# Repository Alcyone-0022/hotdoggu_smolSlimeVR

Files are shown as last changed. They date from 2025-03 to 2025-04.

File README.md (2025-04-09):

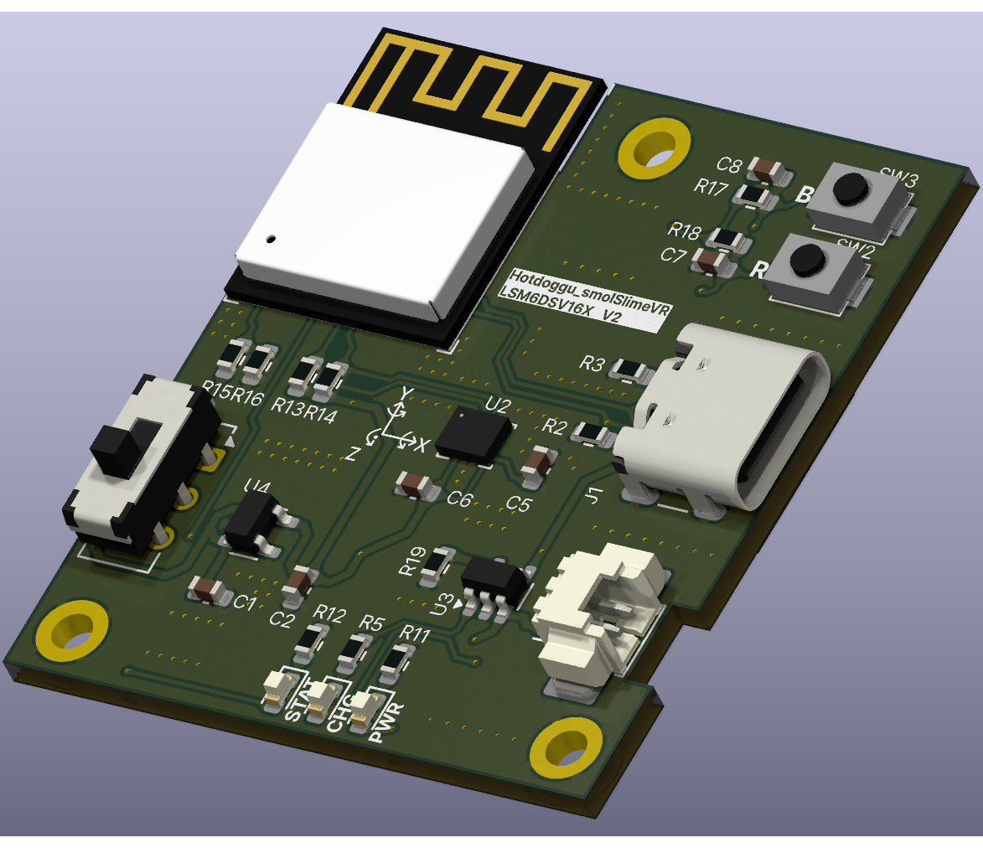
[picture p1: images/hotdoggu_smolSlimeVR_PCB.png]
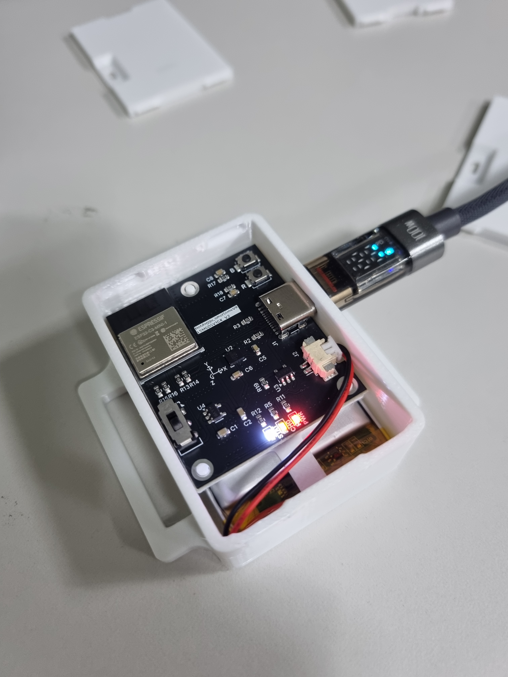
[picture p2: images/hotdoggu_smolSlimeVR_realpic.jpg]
 
# hotdoggu_smolSlimeVR
KiCad project - slimevr tracker using  ESP32-C3-MINI-1, LSM6DSV16X    
Includes 3d-printable case **(for 34\*50\*10(H) Li-Polymer battery)**
# Used Components
### BOM for hotdoggu_smolSlimeVR

| Comment | Designator | Footprint | LCSC | Quantity |
|---|---|---|---|---|
| 10k | R13,R14,R17,R18 | R_0603_1608Metric | C15401 | 4 |
| TYPE-C-31-M-12 | J1 | USB_C_Receptacle_GCT_USB4105-xx-A_16P_TopMnt_Horizontal | C165948 | 1 |
| 1k | R11,R12,R15,R16 | R_0603_1608Metric | C21190 | 4 |
| JS202011CQN | SW1 | SW_CK_JS202011CQN_DPDT_Straight | C221663 | 1 |
| 53261-0271 | J2 | Molex_PicoBlade_53261-0271_1x02-1MP_P1.25mm_Horizontal | C225111 | 1 |
| LED,0603,Red | LED1 | LED_0603_1608Metric | C2286 | 1 |
| 0603,White | LED3 | LED_0603_1608Metric | C2290 | 1 |
| 5.1k, 1% | R2,R3,R5 | R_0603_1608Metric | C23186 | 3 |
| ESP32-C3-MINI-1-H4 | U1 | ESP32-C3-MINI-1 | C2934569 | 1 |
| 2k | R19 | R_0603_1608Metric | C4190 | 1 |
| MCP73831-2-OT | U3 | SOT-23-5 | C424093 | 1 |
| LSM6DSV16X | U2 | LGA-14_3x2.5mm_P0.5mm_LayoutBorder3x4y | C5267406 | 1 |
| 100nF | C5,C6,C7,C8 | C_0603_1608Metric | C66501 | 4 |
| 0603,Yellow | LED2 | LED_0603_1608Metric | C72038 | 1 |
| TS-1088-AR02016 | SW2,SW3 | TS-1088-AR02016 | C720477 | 2 |
| LP5907MFX-3.3 | U4 | SOT-23-5 | C80670 | 1 |
| 10uF | C1,C2 | C_0603_1608Metric | C96446 | 2 | 
### Battery
|Component|Description|Link|
|---|---|----|
|DTP103450|3.7V 1800mAh Li-Polymer battery 34\*50\*10(H)| https://www.devicemart.co.kr/goods/view?no=15285794|
# slimeVR Configuration
**platformio.ini**
```ini
[env:esp32c3]
platform = espressif32 @ 6.7.0
platform_packages =
 framework-arduinoespressif32 @ https://github.com/espressif/arduino-esp32.git#3.0.1
 framework-arduinoespressif32-libs @ https://github.com/espressif/arduino-esp32/releases/download/3.0.1/esp32-arduino-libs-3.0.1.zip
build_flags =
 ${env.build_flags}
 -DESP32C3
board = lolin_c3_mini
```
    
**defines.h**
```C
#define IMU IMU_LSM6DSV
#define SECOND_IMU IMU
#define BOARD BOARD_CUSTOM
#define IMU_ROTATION DEG_0
#define SECOND_IMU_ROTATION DEG_0
#define PRIMARY_IMU_OPTIONAL false
#define SECONDARY_IMU_OPTIONAL true
#define MAX_IMU_COUNT 1
#ifndef IMU_DESC_LIST
#define IMU_DESC_LIST \
    IMU_DESC_ENTRY(IMU,        PRIMARY_IMU_ADDRESS_TWO,   IMU_ROTATION,        PIN_IMU_SCL, PIN_IMU_SDA, PRIMARY_IMU_OPTIONAL, PIN_IMU_INT)
#endif
#define BATTERY_MONITOR BAT_EXTERNAL
#elif BOARD == BOARD_CUSTOM
#define LED_PIN 10
#define LED_INVERTED false
#define PIN_IMU_SDA 3
#define PIN_IMU_SCL 4
#define PIN_IMU_INT 255
#define PIN_IMU_INT_2 255
#define PIN_BATTERY_LEVEL 0
#define BATTERY_SHIELD_RESISTANCE 0
#define BATTERY_SHIELD_R1 1000
#define BATTERY_SHIELD_R2 1000
```

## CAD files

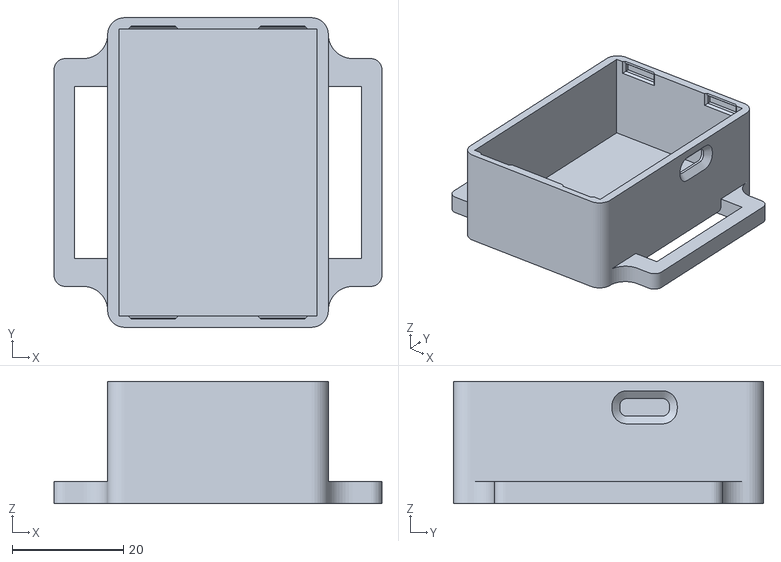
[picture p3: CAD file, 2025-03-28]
STL/main_hotdoggu_smolSlimeVR.stl
59.0 x 55.7 x 22.0

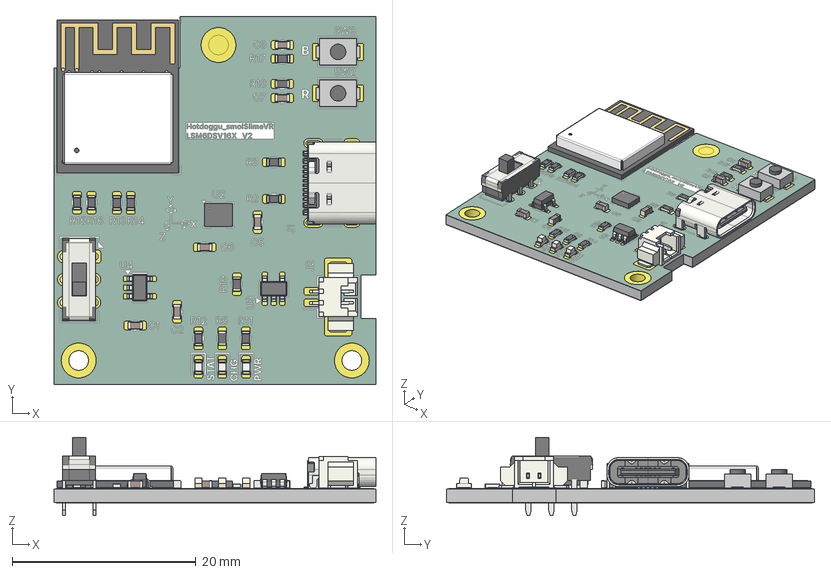
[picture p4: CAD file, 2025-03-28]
hotdoggu_smolSlimeVR_V2.step
35.0 x 40.0 x 8.50 mm
R_0603_1608Metric x 12
SW_CK_JS202011CQN_DPDT_Straight
LGA-14_3x2.5mm_P0.5mm_LayoutBorder3x4y
C_0603_1608Metric x 6
TS-1088-AR020 v2 x 2
TS-1088-AR020 v003 x 2
TS-1088-AR020 v004 x 2
TS-1088-AR020 v005 x 2
Molex_PicoBlade_53261-0271_1x02-1MP_P1.25mm_Horizontal
LED_0603_1608Metric x 3
SOT-23-5 x 2
USB_C_Receptacle_GCT_USB4105-xx-A_16P_TopMnt_Horizontal
DFN1006.STEP^DFN1006.STEP_Submodel-SOD882_part_DesignRootModel_PCB_ ESP32-C3-MINI-1_V1(2)_PCB_ESP32-C3-MINI-1_V1
R0201_20210301.STEP^R0201_20210301.STEP_Submodel-R0201_part_ DesignRootModel_PCB_ESP32-C3-MINI-1_V1(2)_PCB_ESP32-C3-MINI-1_V1 x 3
placementOutline^Submodel-noModelForPart_MINI-ANT-TYPED-H_1968823293_ Submodel-MINI-ANT-TYPED-H_1968823293_part_DesignRootModel_PCB_ ESP32-C3-MINI-1_V1(2)_PCB_E
placementOutline-0^Submodel-noModelForPart_MINI-ANT-TYPED-H_1968823293_ Submodel-MINI-ANT-TYPED-H_1968823293_part_DesignRootModel_PCB_ ESP32-C3-MINI-1_V1(2)_PCB
placementOutline-1^Submodel-noModelForPart_MINI-ANT-TYPED-H_1968823293_ Submodel-MINI-ANT-TYPED-H_1968823293_part_DesignRootModel_PCB_ ESP32-C3-MINI-1_V1(2)_PCB
placementOutline-2^Submodel-noModelForPart_MINI-ANT-TYPED-H_1968823293_ Submodel-MINI-ANT-TYPED-H_1968823293_part_DesignRootModel_PCB_ ESP32-C3-MINI-1_V1(2)_PCB
placementOutline-3^Submodel-noModelForPart_MINI-ANT-TYPED-H_1968823293_ Submodel-MINI-ANT-TYPED-H_1968823293_part_DesignRootModel_PCB_ ESP32-C3-MINI-1_V1(2)_PCB
placementOutline-4^Submodel-noModelForPart_MINI-ANT-TYPED-H_1968823293_ Submodel-MINI-ANT-TYPED-H_1968823293_part_DesignRootModel_PCB_ ESP32-C3-MINI-1_V1(2)_PCB
placementOutline-5^Submodel-noModelForPart_MINI-ANT-TYPED-H_1968823293_ Submodel-MINI-ANT-TYPED-H_1968823293_part_DesignRootModel_PCB_ ESP32-C3-MINI-1_V1(2)_PCB
trace_4^Submodel-MINI-ANT-TYPED-H_1968823293_part_DesignRootModel_PCB_ ESP32-C3-MINI-1_V1(2)_PCB_ESP32-C3-MINI-1_V1
trace_1^Submodel-MINI-ANT-TYPED-H_1968823293_part_DesignRootModel_PCB_ ESP32-C3-MINI-1_V1(2)_PCB_ESP32-C3-MINI-1_V1
C0402_20210301.STEP^C0402_20210301.STEP_Submodel-C0402_part_ DesignRootModel_PCB_ESP32-C3-MINI-1_V1(2)_PCB_ESP32-C3-MINI-1_V1
C0201_20210301.STEP^C0201_20210301.STEP_Submodel-C0201_part_ DesignRootModel_PCB_ESP32-C3-MINI-1_V1(2)_PCB_ESP32-C3-MINI-1_V1 x 11
L0201_20210301.STEP^L0201_20210301.STEP_Submodel-L0201_part_ DesignRootModel_PCB_ESP32-C3-MINI-1_V1(2)_PCB_ESP32-C3-MINI-1_V1 x 2
XTAL3225_20210301.STEP^XTAL3225_20210301.STEP_Submodel-XTAL3225_part_ DesignRootModel_PCB_ESP32-C3-MINI-1_V1(2)_PCB_ESP32-C3-MINI-1_V1
ESP32-C3_20210301.STEP^ESP32-C3_20210301.STEP_Submodel-QFN32_0P5_5_ part_DesignRootModel_PCB_ESP32-C3-MINI-1_V1(2)_PCB_ESP32-C3-MINI-1_V1
uid__4^DesignRootModel_PCB_ESP32-C3-MINI-1_V1(2)_PCB_ESP32-C3-MINI-1_ V1
uid__4-22^DesignRootModel_PCB_ESP32-C3-MINI-1_V1(2)_PCB_ ESP32-C3-MINI-1_V1
uid__4-23^DesignRootModel_PCB_ESP32-C3-MINI-1_V1(2)_PCB_ ESP32-C3-MINI-1_V1
uid__4-24^DesignRootModel_PCB_ESP32-C3-MINI-1_V1(2)_PCB_ ESP32-C3-MINI-1_V1
uid__4-25^DesignRootModel_PCB_ESP32-C3-MINI-1_V1(2)_PCB_ ESP32-C3-MINI-1_V1
uid__4-26^DesignRootModel_PCB_ESP32-C3-MINI-1_V1(2)_PCB_ ESP32-C3-MINI-1_V1
uid__4-27^DesignRootModel_PCB_ESP32-C3-MINI-1_V1(2)_PCB_ ESP32-C3-MINI-1_V1
uid__4-28^DesignRootModel_PCB_ESP32-C3-MINI-1_V1(2)_PCB_ ESP32-C3-MINI-1_V1
uid__4-29^DesignRootModel_PCB_ESP32-C3-MINI-1_V1(2)_PCB_ ESP32-C3-MINI-1_V1
uid__4-30^DesignRootModel_PCB_ESP32-C3-MINI-1_V1(2)_PCB_ ESP32-C3-MINI-1_V1
uid__4-31^DesignRootModel_PCB_ESP32-C3-MINI-1_V1(2)_PCB_ ESP32-C3-MINI-1_V1
uid__4-32^DesignRootModel_PCB_ESP32-C3-MINI-1_V1(2)_PCB_ ESP32-C3-MINI-1_V1
uid__4-33^DesignRootModel_PCB_ESP32-C3-MINI-1_V1(2)_PCB_ ESP32-C3-MINI-1_V1
uid__4-34^DesignRootModel_PCB_ESP32-C3-MINI-1_V1(2)_PCB_ ESP32-C3-MINI-1_V1
uid__4-35^DesignRootModel_PCB_ESP32-C3-MINI-1_V1(2)_PCB_ ESP32-C3-MINI-1_V1
uid__4-36^DesignRootModel_PCB_ESP32-C3-MINI-1_V1(2)_PCB_ ESP32-C3-MINI-1_V1
uid__4-37^DesignRootModel_PCB_ESP32-C3-MINI-1_V1(2)_PCB_ ESP32-C3-MINI-1_V1
uid__4-38^DesignRootModel_PCB_ESP32-C3-MINI-1_V1(2)_PCB_ ESP32-C3-MINI-1_V1
uid__4-39^DesignRootModel_PCB_ESP32-C3-MINI-1_V1(2)_PCB_ ESP32-C3-MINI-1_V1
uid__4-40^DesignRootModel_PCB_ESP32-C3-MINI-1_V1(2)_PCB_ ESP32-C3-MINI-1_V1
uid__4-41^DesignRootModel_PCB_ESP32-C3-MINI-1_V1(2)_PCB_ ESP32-C3-MINI-1_V1
uid__4-42^DesignRootModel_PCB_ESP32-C3-MINI-1_V1(2)_PCB_ ESP32-C3-MINI-1_V1
uid__4-43^DesignRootModel_PCB_ESP32-C3-MINI-1_V1(2)_PCB_ ESP32-C3-MINI-1_V1
uid__4-44^DesignRootModel_PCB_ESP32-C3-MINI-1_V1(2)_PCB_ ESP32-C3-MINI-1_V1
uid__4-45^DesignRootModel_PCB_ESP32-C3-MINI-1_V1(2)_PCB_ ESP32-C3-MINI-1_V1
uid__4-46^DesignRootModel_PCB_ESP32-C3-MINI-1_V1(2)_PCB_ ESP32-C3-MINI-1_V1
uid__4-47^DesignRootModel_PCB_ESP32-C3-MINI-1_V1(2)_PCB_ ESP32-C3-MINI-1_V1
uid__4-48^DesignRootModel_PCB_ESP32-C3-MINI-1_V1(2)_PCB_ ESP32-C3-MINI-1_V1
uid__4-49^DesignRootModel_PCB_ESP32-C3-MINI-1_V1(2)_PCB_ ESP32-C3-MINI-1_V1
uid__4-50^DesignRootModel_PCB_ESP32-C3-MINI-1_V1(2)_PCB_ ESP32-C3-MINI-1_V1
uid__4-51^DesignRootModel_PCB_ESP32-C3-MINI-1_V1(2)_PCB_ ESP32-C3-MINI-1_V1
uid__4-52^DesignRootModel_PCB_ESP32-C3-MINI-1_V1(2)_PCB_ ESP32-C3-MINI-1_V1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

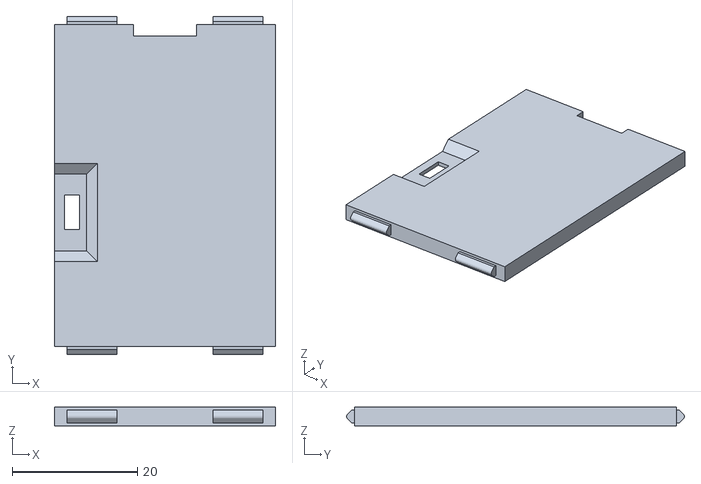
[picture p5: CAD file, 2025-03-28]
STL/Lid_hotdoggu_smolSlimeVR.stl
35.3 x 53.9 x 3.00

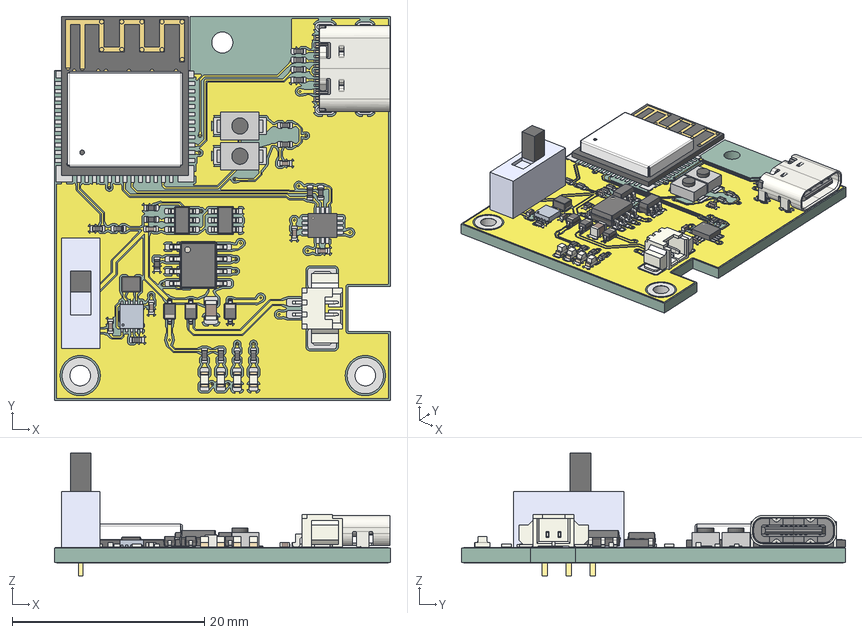
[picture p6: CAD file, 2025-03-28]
hotdoggu_smolSlimeVR.step
35.0 x 40.0 x 12.8 mm
C_0402_1005Metric x 6
USB_C_Receptacle_GCT_USB4105-xx-A_16P_TopMnt_Horizontal
SOT-23-6 x 2
LED_0603_1608Metric x 4
L_Cenker_CKCS201610
R_0402_1005Metric x 18
D_SOD-323 x 3
Molex_PicoBlade_53261-0271_1x02-1MP_P1.25mm_Horizontal
MSL-1C2P SW
TS-1088-AR020 v2 x 2
TS-1088-AR020 v003 x 2
TS-1088-AR020 v004 x 2
TS-1088-AR020 v005 x 2
hotdoggu_smolSlimeVR 1.20.1
C_0805_2012Metric
LGA-14_3x2.5mm_P0.5mm_LayoutBorder3x4y
SOIC-8_3.9x4.9mm_P1.27mm
DFN1006.STEP^DFN1006.STEP_Submodel-SOD882_part_DesignRootModel_PCB_ ESP32-C3-MINI-1_V1(2)_PCB_ESP32-C3-MINI-1_V1
R0201_20210301.STEP^R0201_20210301.STEP_Submodel-R0201_part_ DesignRootModel_PCB_ESP32-C3-MINI-1_V1(2)_PCB_ESP32-C3-MINI-1_V1 x 3
placementOutline^Submodel-noModelForPart_MINI-ANT-TYPED-H_1968823293_ Submodel-MINI-ANT-TYPED-H_1968823293_part_DesignRootModel_PCB_ ESP32-C3-MINI-1_V1(2)_PCB_E
placementOutline-0^Submodel-noModelForPart_MINI-ANT-TYPED-H_1968823293_ Submodel-MINI-ANT-TYPED-H_1968823293_part_DesignRootModel_PCB_ ESP32-C3-MINI-1_V1(2)_PCB
placementOutline-1^Submodel-noModelForPart_MINI-ANT-TYPED-H_1968823293_ Submodel-MINI-ANT-TYPED-H_1968823293_part_DesignRootModel_PCB_ ESP32-C3-MINI-1_V1(2)_PCB
placementOutline-2^Submodel-noModelForPart_MINI-ANT-TYPED-H_1968823293_ Submodel-MINI-ANT-TYPED-H_1968823293_part_DesignRootModel_PCB_ ESP32-C3-MINI-1_V1(2)_PCB
placementOutline-3^Submodel-noModelForPart_MINI-ANT-TYPED-H_1968823293_ Submodel-MINI-ANT-TYPED-H_1968823293_part_DesignRootModel_PCB_ ESP32-C3-MINI-1_V1(2)_PCB
placementOutline-4^Submodel-noModelForPart_MINI-ANT-TYPED-H_1968823293_ Submodel-MINI-ANT-TYPED-H_1968823293_part_DesignRootModel_PCB_ ESP32-C3-MINI-1_V1(2)_PCB
placementOutline-5^Submodel-noModelForPart_MINI-ANT-TYPED-H_1968823293_ Submodel-MINI-ANT-TYPED-H_1968823293_part_DesignRootModel_PCB_ ESP32-C3-MINI-1_V1(2)_PCB
trace_4^Submodel-MINI-ANT-TYPED-H_1968823293_part_DesignRootModel_PCB_ ESP32-C3-MINI-1_V1(2)_PCB_ESP32-C3-MINI-1_V1
trace_1^Submodel-MINI-ANT-TYPED-H_1968823293_part_DesignRootModel_PCB_ ESP32-C3-MINI-1_V1(2)_PCB_ESP32-C3-MINI-1_V1
C0402_20210301.STEP^C0402_20210301.STEP_Submodel-C0402_part_ DesignRootModel_PCB_ESP32-C3-MINI-1_V1(2)_PCB_ESP32-C3-MINI-1_V1
C0201_20210301.STEP^C0201_20210301.STEP_Submodel-C0201_part_ DesignRootModel_PCB_ESP32-C3-MINI-1_V1(2)_PCB_ESP32-C3-MINI-1_V1 x 11
L0201_20210301.STEP^L0201_20210301.STEP_Submodel-L0201_part_ DesignRootModel_PCB_ESP32-C3-MINI-1_V1(2)_PCB_ESP32-C3-MINI-1_V1 x 2
XTAL3225_20210301.STEP^XTAL3225_20210301.STEP_Submodel-XTAL3225_part_ DesignRootModel_PCB_ESP32-C3-MINI-1_V1(2)_PCB_ESP32-C3-MINI-1_V1
ESP32-C3_20210301.STEP^ESP32-C3_20210301.STEP_Submodel-QFN32_0P5_5_ part_DesignRootModel_PCB_ESP32-C3-MINI-1_V1(2)_PCB_ESP32-C3-MINI-1_V1
uid__4^DesignRootModel_PCB_ESP32-C3-MINI-1_V1(2)_PCB_ESP32-C3-MINI-1_ V1
uid__4-22^DesignRootModel_PCB_ESP32-C3-MINI-1_V1(2)_PCB_ ESP32-C3-MINI-1_V1
uid__4-23^DesignRootModel_PCB_ESP32-C3-MINI-1_V1(2)_PCB_ ESP32-C3-MINI-1_V1
uid__4-24^DesignRootModel_PCB_ESP32-C3-MINI-1_V1(2)_PCB_ ESP32-C3-MINI-1_V1
uid__4-25^DesignRootModel_PCB_ESP32-C3-MINI-1_V1(2)_PCB_ ESP32-C3-MINI-1_V1
uid__4-26^DesignRootModel_PCB_ESP32-C3-MINI-1_V1(2)_PCB_ ESP32-C3-MINI-1_V1
uid__4-27^DesignRootModel_PCB_ESP32-C3-MINI-1_V1(2)_PCB_ ESP32-C3-MINI-1_V1
uid__4-28^DesignRootModel_PCB_ESP32-C3-MINI-1_V1(2)_PCB_ ESP32-C3-MINI-1_V1
uid__4-29^DesignRootModel_PCB_ESP32-C3-MINI-1_V1(2)_PCB_ ESP32-C3-MINI-1_V1
uid__4-30^DesignRootModel_PCB_ESP32-C3-MINI-1_V1(2)_PCB_ ESP32-C3-MINI-1_V1
uid__4-31^DesignRootModel_PCB_ESP32-C3-MINI-1_V1(2)_PCB_ ESP32-C3-MINI-1_V1
uid__4-32^DesignRootModel_PCB_ESP32-C3-MINI-1_V1(2)_PCB_ ESP32-C3-MINI-1_V1
uid__4-33^DesignRootModel_PCB_ESP32-C3-MINI-1_V1(2)_PCB_ ESP32-C3-MINI-1_V1
uid__4-34^DesignRootModel_PCB_ESP32-C3-MINI-1_V1(2)_PCB_ ESP32-C3-MINI-1_V1
uid__4-35^DesignRootModel_PCB_ESP32-C3-MINI-1_V1(2)_PCB_ ESP32-C3-MINI-1_V1
uid__4-36^DesignRootModel_PCB_ESP32-C3-MINI-1_V1(2)_PCB_ ESP32-C3-MINI-1_V1
uid__4-37^DesignRootModel_PCB_ESP32-C3-MINI-1_V1(2)_PCB_ ESP32-C3-MINI-1_V1
uid__4-38^DesignRootModel_PCB_ESP32-C3-MINI-1_V1(2)_PCB_ ESP32-C3-MINI-1_V1
uid__4-39^DesignRootModel_PCB_ESP32-C3-MINI-1_V1(2)_PCB_ ESP32-C3-MINI-1_V1
uid__4-40^DesignRootModel_PCB_ESP32-C3-MINI-1_V1(2)_PCB_ ESP32-C3-MINI-1_V1
uid__4-41^DesignRootModel_PCB_ESP32-C3-MINI-1_V1(2)_PCB_ ESP32-C3-MINI-1_V1
uid__4-42^DesignRootModel_PCB_ESP32-C3-MINI-1_V1(2)_PCB_ ESP32-C3-MINI-1_V1
uid__4-43^DesignRootModel_PCB_ESP32-C3-MINI-1_V1(2)_PCB_ ESP32-C3-MINI-1_V1
uid__4-44^DesignRootModel_PCB_ESP32-C3-MINI-1_V1(2)_PCB_ ESP32-C3-MINI-1_V1
uid__4-45^DesignRootModel_PCB_ESP32-C3-MINI-1_V1(2)_PCB_ ESP32-C3-MINI-1_V1
uid__4-46^DesignRootModel_PCB_ESP32-C3-MINI-1_V1(2)_PCB_ ESP32-C3-MINI-1_V1
uid__4-47^DesignRootModel_PCB_ESP32-C3-MINI-1_V1(2)_PCB_ ESP32-C3-MINI-1_V1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

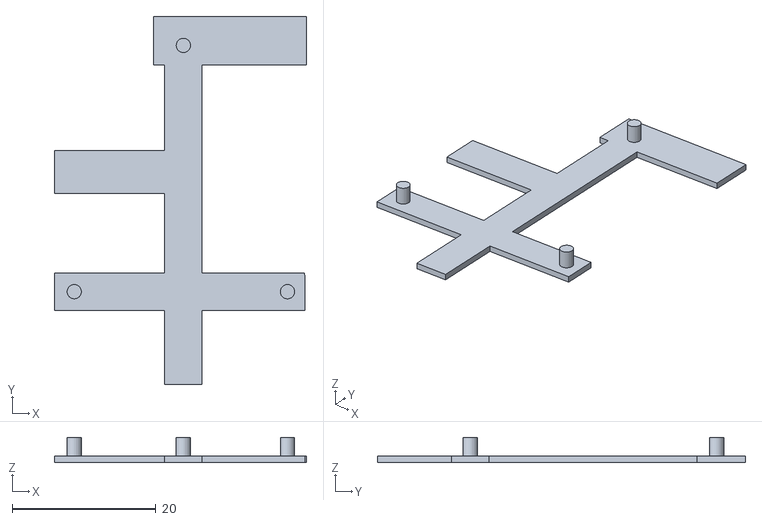
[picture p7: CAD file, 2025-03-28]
STL/spacer_hotdoggu_smolSlimeVR.stl
35.1 x 51.3 x 3.50

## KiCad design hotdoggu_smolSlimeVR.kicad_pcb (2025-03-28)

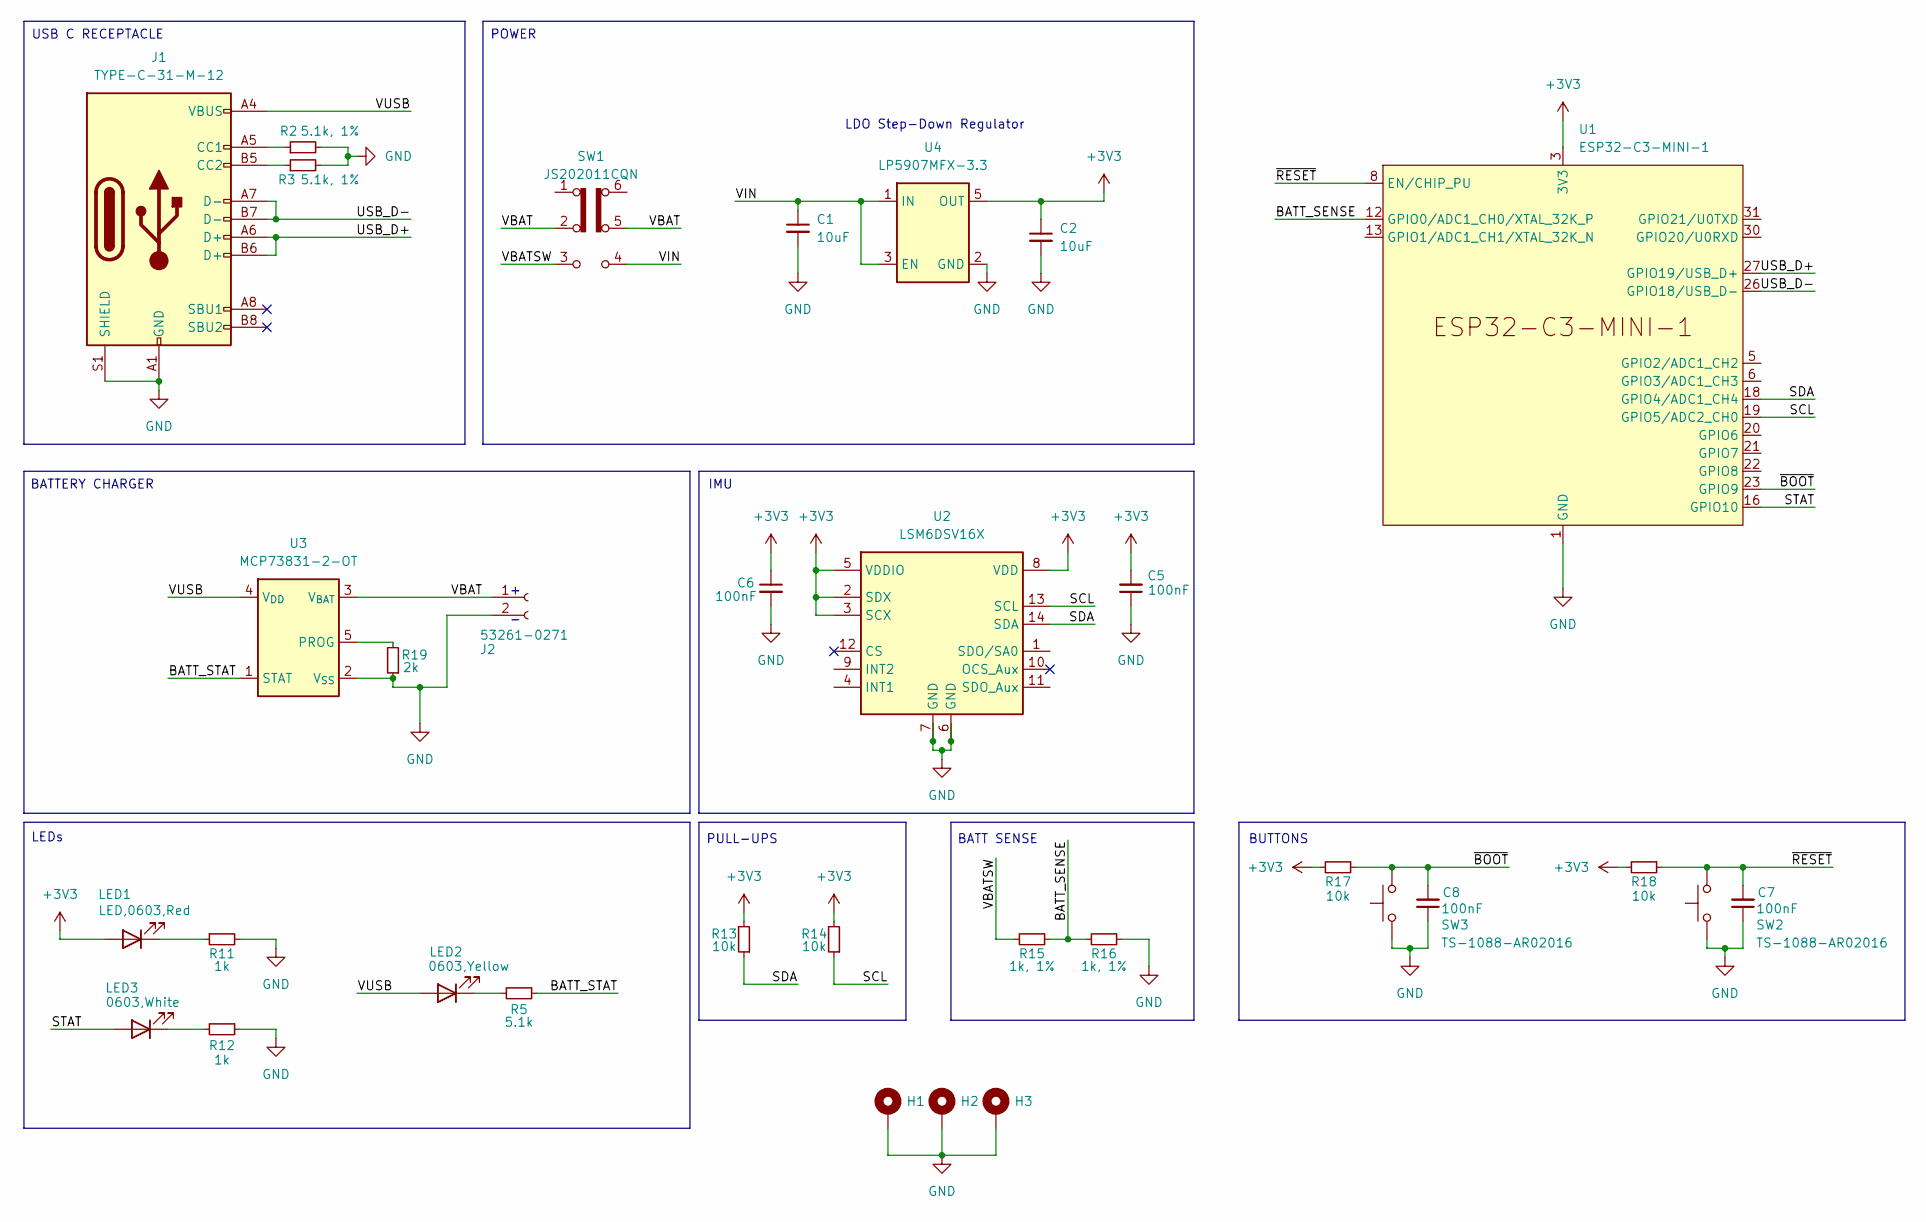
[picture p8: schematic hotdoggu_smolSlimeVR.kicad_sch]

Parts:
C1, C2: 10uF; C_0603_1608Metric
C5, C6, C7, C8: 100nF; C_0603_1608Metric
H1, H2, H3: MountingHole; MountingHole_2.2mm_M2_DIN965_Pad_TopBottom
J1: TYPE-C-31-M-12; USB_C_Receptacle_GCT_USB4105-xx-A_16P_TopMnt_Horizontal
J2: 53261-0271; Molex_PicoBlade_53261-0271_1x02-1MP_P1.25mm_Horizontal
LED1: LED,0603,Red; LED_0603_1608Metric
LED2: 0603,Yellow; LED_0603_1608Metric
LED3: 0603,White; LED_0603_1608Metric
R2, R3: 5.1k, 1%; R_0603_1608Metric
R5: 5.1k; R_0603_1608Metric
R11, R12: 1k; R_0603_1608Metric
R13, R14, R17, R18: 10k; R_0603_1608Metric
R15, R16: 1k, 1%; R_0603_1608Metric
R19: 2k; R_0603_1608Metric
SW1: JS202011CQN; SW_CK_JS202011CQN_DPDT_Straight
SW2, SW3: TS-1088-AR02016
U1: ESP32-C3-MINI-1
U2: LSM6DSV16X; LGA-14_3x2.5mm_P0.5mm_LayoutBorder3x4y
U3: MCP73831-2-OT; SOT-23-5
U4: LP5907MFX-3.3; SOT-23-5

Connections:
+3V3: C2.1, C5.2, C6.1, LED1.2 (A), R13.2, R14.2, R17.2, R18.2, U1.3 (3V3), U2.2 (SDX), U2.3 (SCX), U2.5 (VDDIO), U2.8 (VDD), U4.5 (OUT)
/BATT_SENSE: R15.1, R16.2, U1.12 (GPIO0/ADC1_CH0/XTAL_32K_P)
/BATT_STAT: R5.1, U3.1 (STAT)
/SCL: R14.1, U1.19 (GPIO5/ADC2_CH0), U2.13 (SCL)
/SDA: R13.1, U1.18 (GPIO4/ADC1_CH4), U2.14 (SDA)
/STAT: LED3.2 (A), U1.16 (GPIO10)
/USB_D+: J1.A6 (D+), J1.B6 (D+), U1.27 (GPIO19/USB_D+)
/USB_D-: J1.A7 (D-), J1.B7 (D-), U1.26 (GPIO18/USB_D-)
/VBAT: J2.1, SW1.2 (B), SW1.5 (B), U3.3 (V_{BAT})
/VBATSW: R15.2, SW1.3 (C)
/VIN: C1.1, SW1.4 (A), U4.1 (IN), U4.3 (EN)
/VUSB: J1.A4 (VBUS), J1.A9 (VBUS), J1.B4 (VBUS), J1.B9 (VBUS), LED2.2 (A), U3.4 (V_{DD})
/~BOOT: C8.2, R17.1, SW3.2, U1.23 (GPIO9)
/~RESET: C7.2, R18.1, SW2.2, U1.8 (EN/CHIP_PU)
GND: C1.2, C2.2, C5.1, C6.2, C7.1, C8.1, H1.1, H2.1, H3.1, J1.A1 (GND), J1.A12 (GND), J1.B1 (GND), J1.B12 (GND), J1.S1 (SHIELD), J2.2, R2.2, R3.2, R11.2, R12.1, R16.1, R19.1, SW2.1, SW3.1, U1.1 (GND), U1.2 (GND), U1.11 (GND), U1.14 (GND), U1.36 (GND), U1.37 (GND), U1.38 (GND), U1.39 (GND), U1.40 (GND), U1.41 (GND), U1.42 (GND), U1.43 (GND), U1.44 (GND), U1.45 (GND), U1.46 (GND), U1.47 (GND), U1.48 (GND), U1.49 (GND), U1.50 (GND), U1.51 (GND), U1.52 (GND), U1.53 (GND), U2.6 (GND), U2.7 (GND), U3.2 (V_{SS}), U4.2 (GND)
unnamed: J1.A5 (CC1), R2.1
unnamed: J1.B5 (CC2), R3.1
unnamed: LED1.1 (K), R11.1
unnamed: LED2.1 (K), R5.2
unnamed: LED3.1 (K), R12.2
unnamed: R19.2, U3.5 (PROG)

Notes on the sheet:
USB C RECEPTACLE
BATTERY CHARGER
LEDs
IMU
POWER
BUTTONS
PULL-UPS
LDO Step-Down Regulator
+ -
BATT SENSE

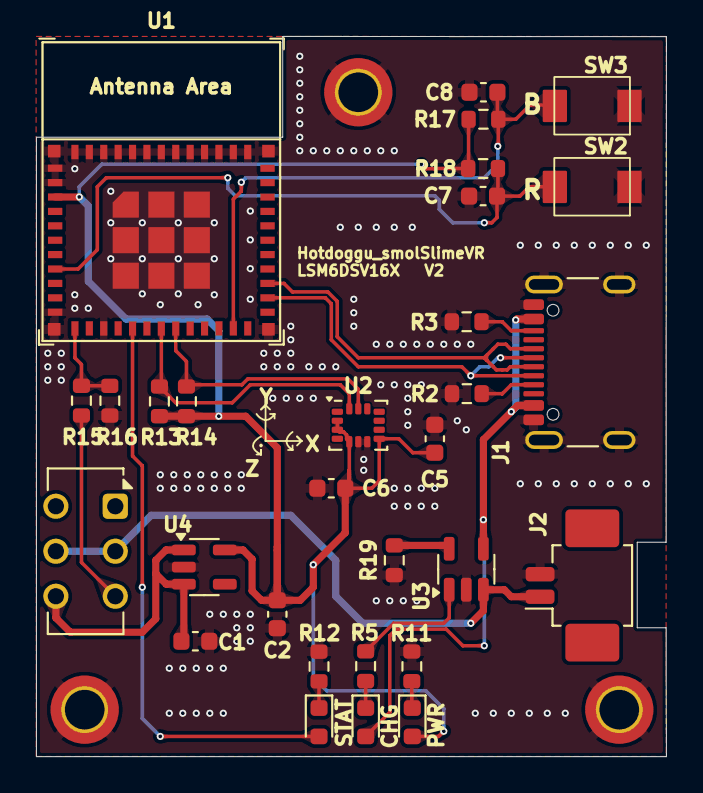
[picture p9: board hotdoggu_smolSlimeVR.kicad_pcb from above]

Board: 2 copper layers, 35.0 x 40.0 mm, 33 parts (0 on the bottom side), 21 nets.

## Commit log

2025-03-07 initial commit, rev 1
    [BOM-hotdoggu_smolSlimeVR.csv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]
2025-03-28 Hotdoggu_smolSlimeVR V2
    [BOM-hotdoggu_smolSlimeVR.csv, Lid_hotdoggu_smolSlimeVR.stl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]
